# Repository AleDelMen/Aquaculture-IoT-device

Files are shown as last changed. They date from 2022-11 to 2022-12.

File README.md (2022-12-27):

# Design and development of a water quality measurement prototype for aquaculture production

This project presents the development of a system for monitoring and data collection. The system is composed of a device for measuring parameters related to a phenomenon of interest called end device, a gateway that is in charge of receiving the data, an application server that stores, displays and triggers alarms if necessary, and a network server that coordinates the gateway and the application server. As a demonstration of the system, a fish farm water quality monitoring application is shown, however, the proposed system is general purpose, and can be used in a wide variety of IoT applications.

## System operation

The block diagram of the project can be seen in the following figure. 

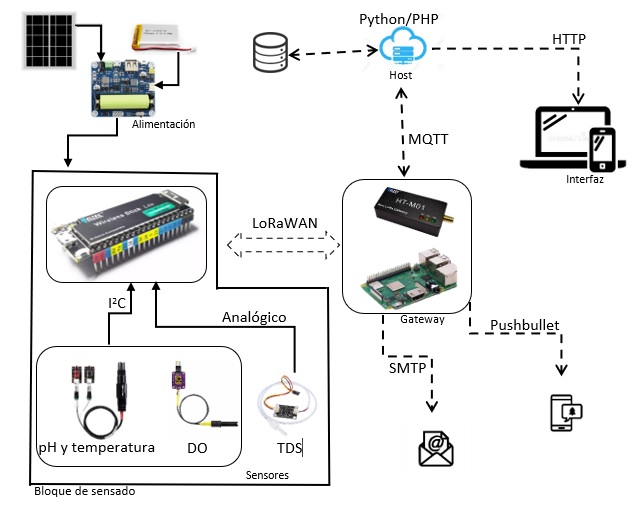
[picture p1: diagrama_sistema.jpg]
System diagram


The diagram shows that the sensing block is powered by solar panels or rechargeable batteries.
In this block, the Wireless Stick Lite board is in charge of controlling and collecting the information from the sensors through the i2c communication protocol and through an analog channel. Once the information is collected, it is transmitted from the control board to the gateway using the LoRaWAN protocol. 

The HT-M01 module controlled through a Raspberry Pi 3B+ was used as the gateway. The ChirpStack network server stack was also installed on the computer to carry out the LoRaWAN network implementation. The ChirpStack stack is responsible for sharing the information received from the sensing block to the host so that the host can process it. Chirpstack uses the MQTT protocol to communicate the data.

The host is in charge of processing the information through a Python script. If any irregularity is found in the data received, a digital alert is triggered and sent via email through the SMTP protocol or it can also be sent via push notification using the Pushbullet application. Additionally, the host is responsible for storing the information in a database and hosts a web page through which the data can be consulted in real time.

The web page was built using the adminLTE template as a base, together with HTML, CSS, native PHP, JavaScript, MariaDB technologies and phpMyAdmin was used as database manager. 

## Implementation
The water quality monitoring system developed in this work was implemented and evaluated in experimental shrimp, abalone, striped bass, koi carp and pismo clams farms located in the CICESE. Measurements were taken every minute, obtaining about 1440 samples per day versus two that are usually taken manually in these cultures.

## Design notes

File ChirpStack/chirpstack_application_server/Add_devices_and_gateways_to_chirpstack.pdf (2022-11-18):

# Add devices and gateways to ChirpStack

### October 2022

## 1 Create an organization

In order to add gateways and devices to ChirpStack, an organization needs to be created. Below are the steps to follow.

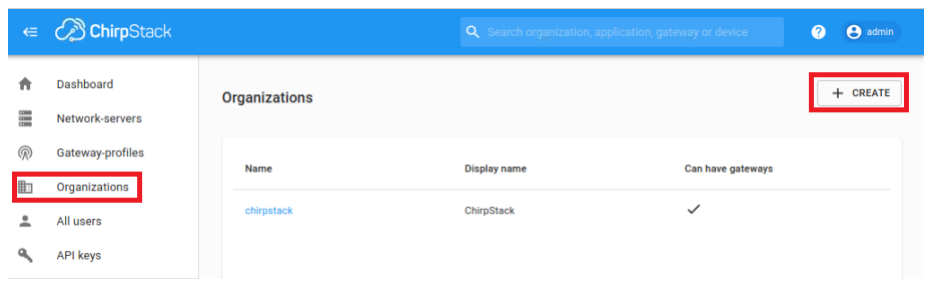
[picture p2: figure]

Figure 1: Tab to create an organization.

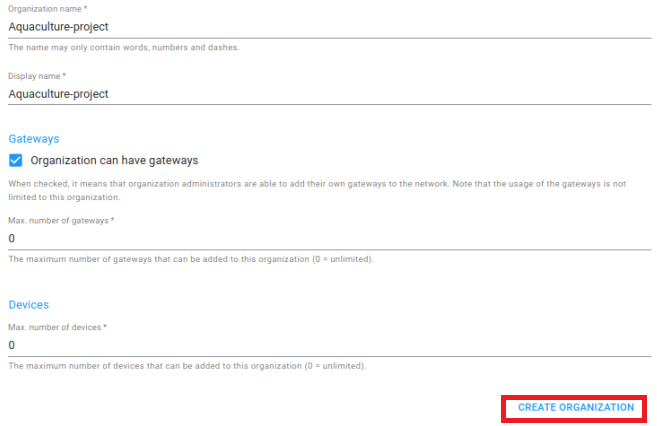
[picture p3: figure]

Figure 2: Fill in the organization data and press "create organization".

## 2 Create the Network Server

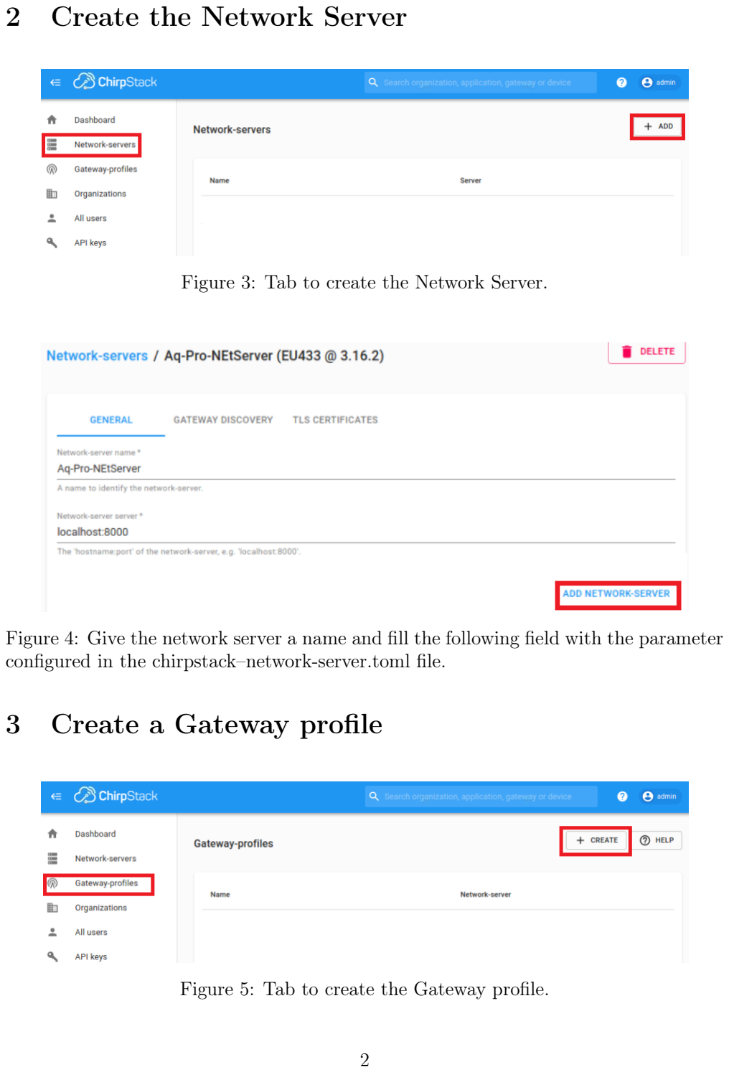
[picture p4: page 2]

Figure 3: Tab to create the Network Server.

Figure 4: Give the network server a name and fill the following field with the parameter configured in the chirpstack–network-server.toml file.

## 3 Create a Gateway profile

Figure 5: Tab to create the Gateway profile.

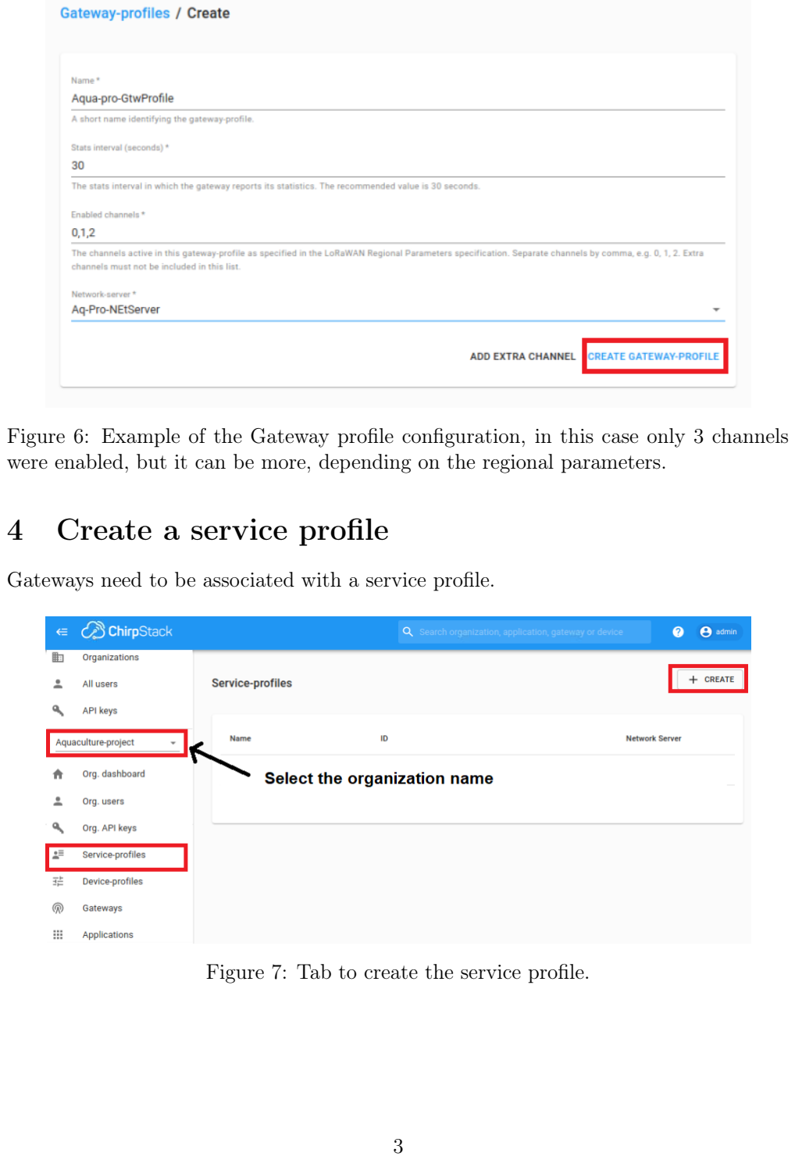
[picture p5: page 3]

Figure 6: Example of the Gateway profile configuration, in this case only 3 channels were enabled, but it can be more, depending on the regional parameters.

## 4 Create a service profile

Gateways need to be associated with a service profile.

Figure 7: Tab to create the service profile.

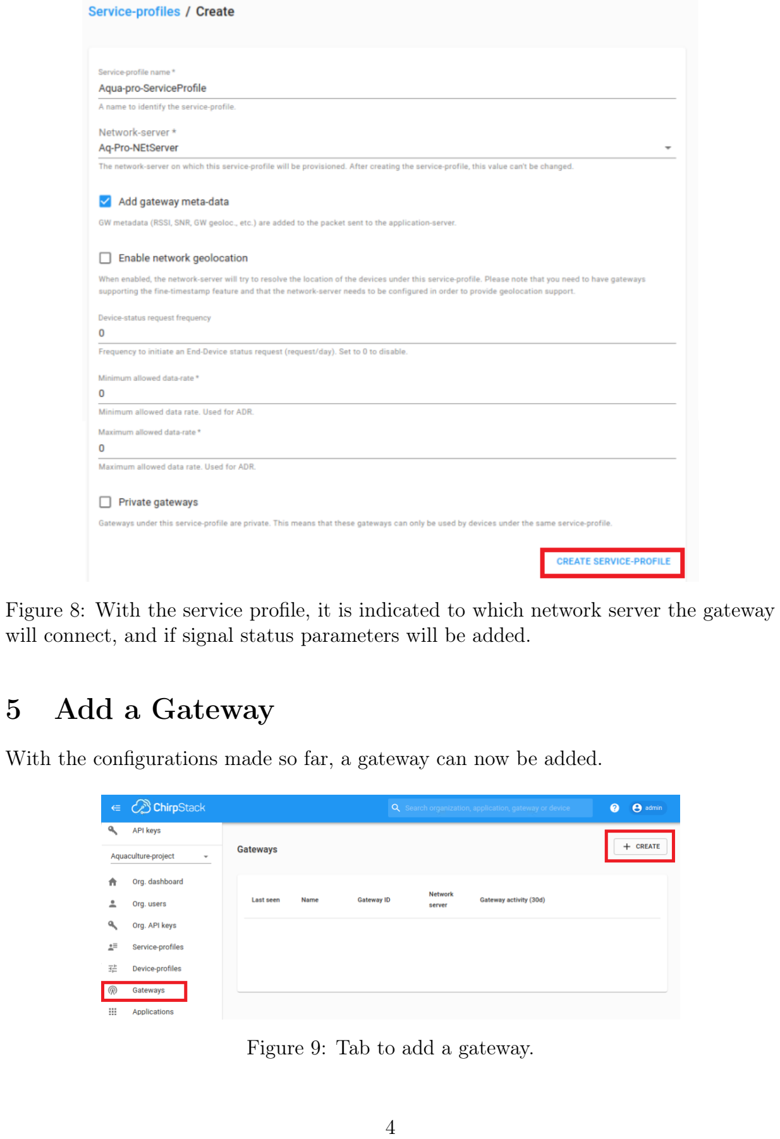
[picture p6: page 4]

Figure 8: With the service profile, it is indicated to which network server the gateway will connect, and if signal status parameters will be added.

## 5 Add a Gateway

With the configurations made so far, a gateway can now be added.

Figure 9: Tab to add a gateway.

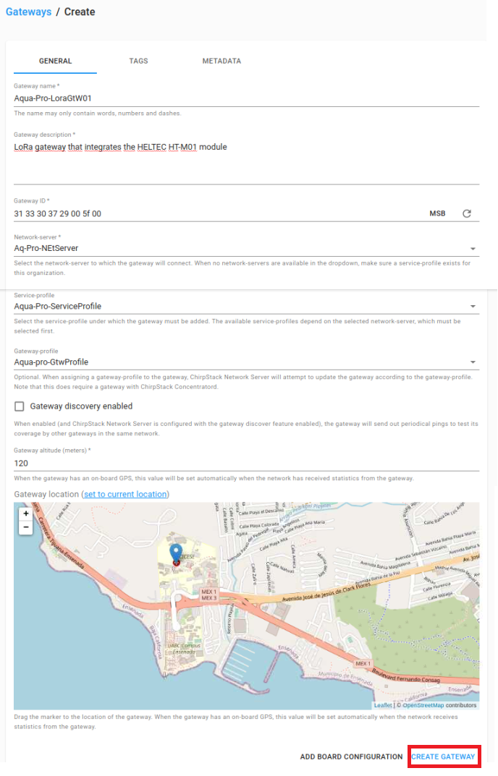
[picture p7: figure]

Figure 10: To add the gateway, all the previously created resources are needed, in addition to the Gateway_ID.

At the end of the registration process, it is possible to observe that the least seen status is a few seconds ago.

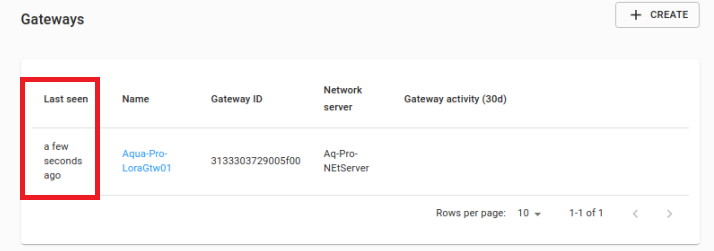
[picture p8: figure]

Figure 11: Gateway status at the end of the registration process.

It is also possible to see the status of the gateway in the main dashboard of the organization.

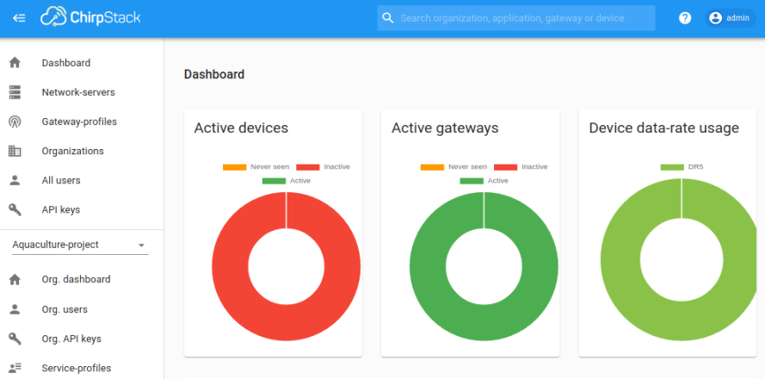
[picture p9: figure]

Figure 12: Gateway status on dashboard.

## 6 Create a device profile

To begin the process of registering a device on ChirpStack, you must already have the service profile. The device profile describes how to connect and authenticate a group of devices.

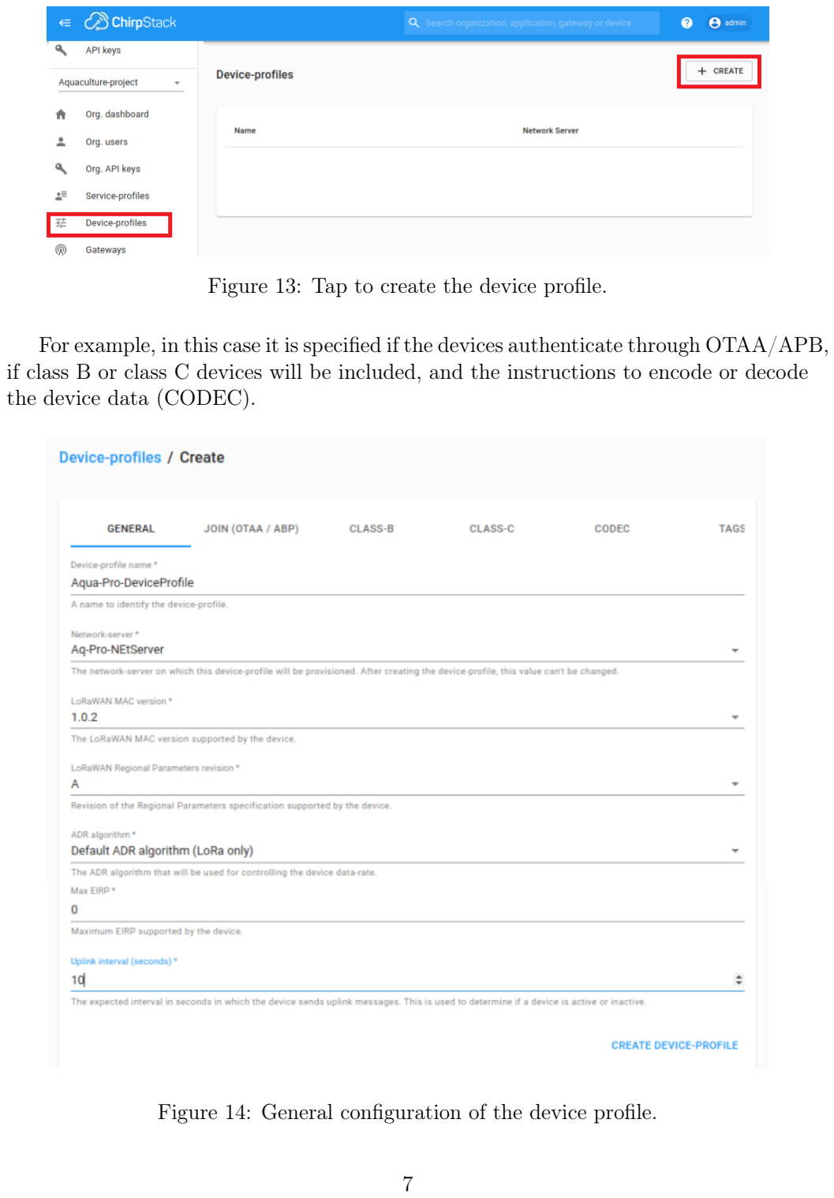
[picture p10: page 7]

Figure 13: Tap to create the device profile.

For example, in this case it is specified if the devices authenticate through OTAA/APB, if class B or class C devices will be included, and the instructions to encode or decode the device data (CODEC).

Figure 14: General configuration of the device profile.

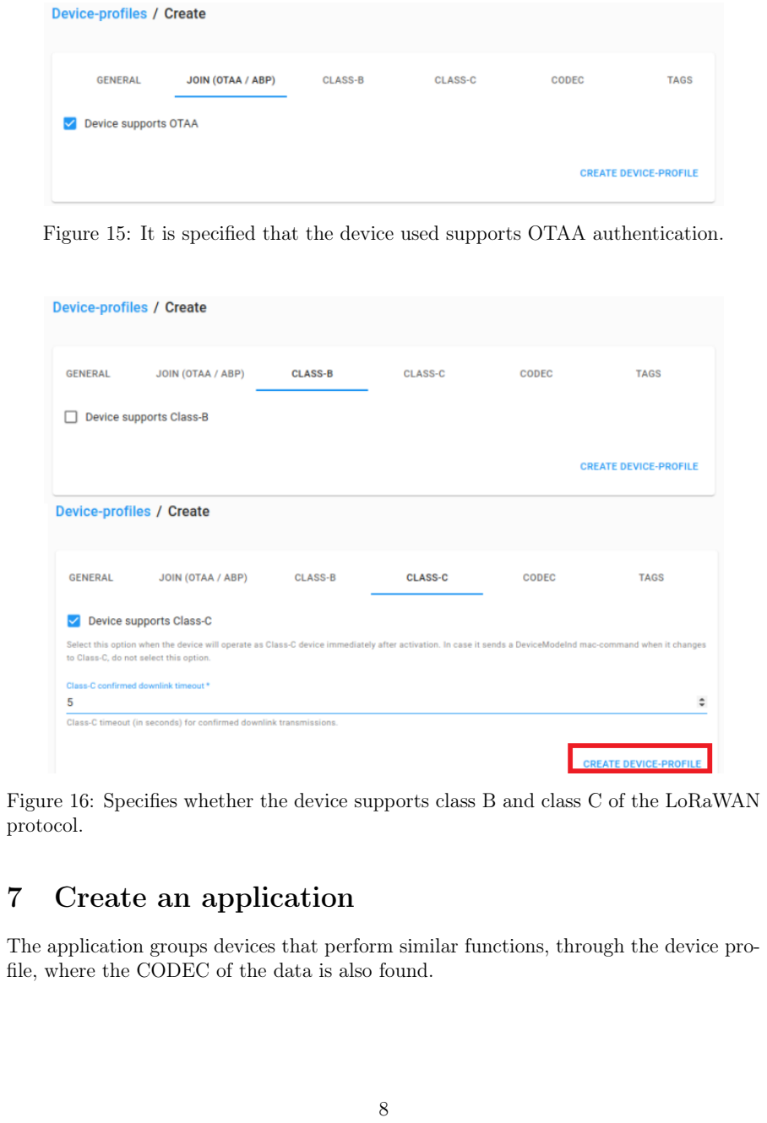
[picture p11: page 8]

Figure 15: It is specified that the device used supports OTAA authentication.

Figure 16: Specifies whether the device supports class B and class C of the LoRaWAN protocol.

## 7 Create an application

The application groups devices that perform similar functions, through the device profile, where the CODEC of the data is also found.

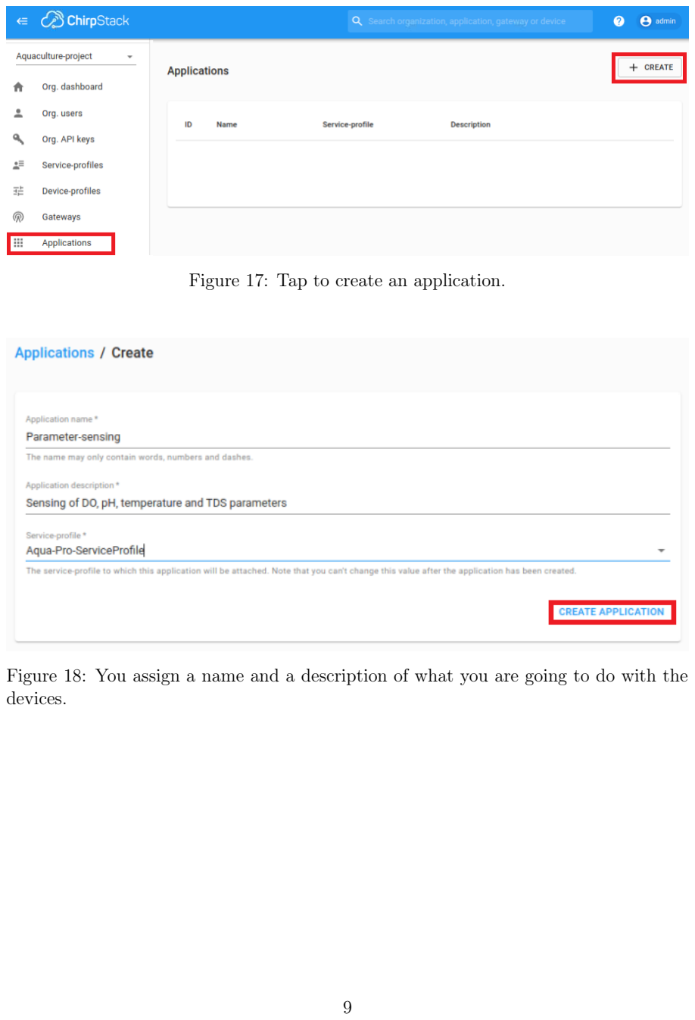
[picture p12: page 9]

Figure 17: Tap to create an application.

Figure 18: You assign a name and a description of what you are going to do with the devices.

## 8 Add devices to the app

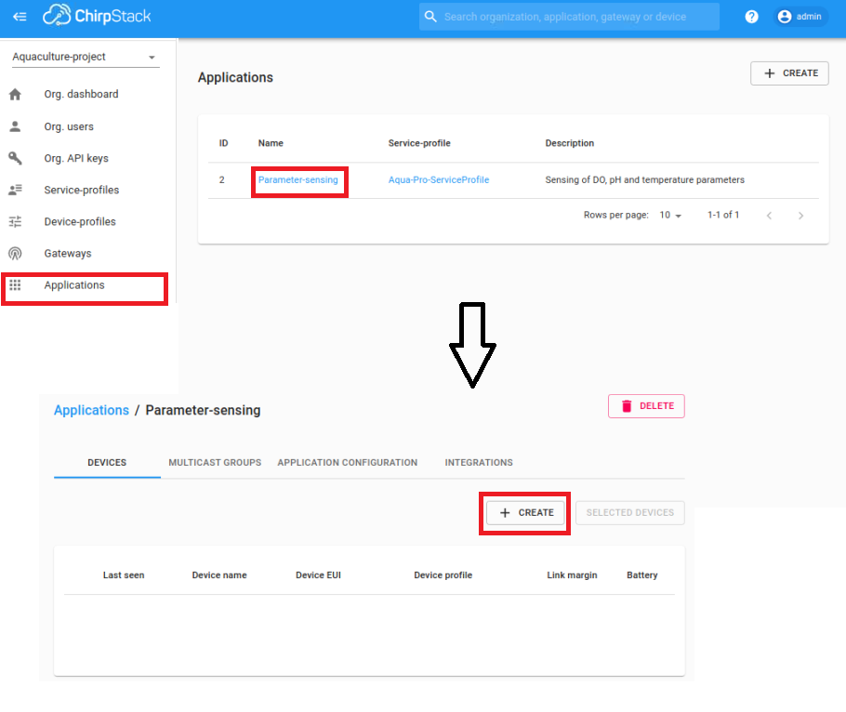
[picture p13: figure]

Figure 19: Path to follow to add devices to the app.

Device EUI is primary for OTAA connection. The Device EUI can be generated with the button displayed on the screen and is used in device programming.
The device profile is selected from the tab and the options are displayed.

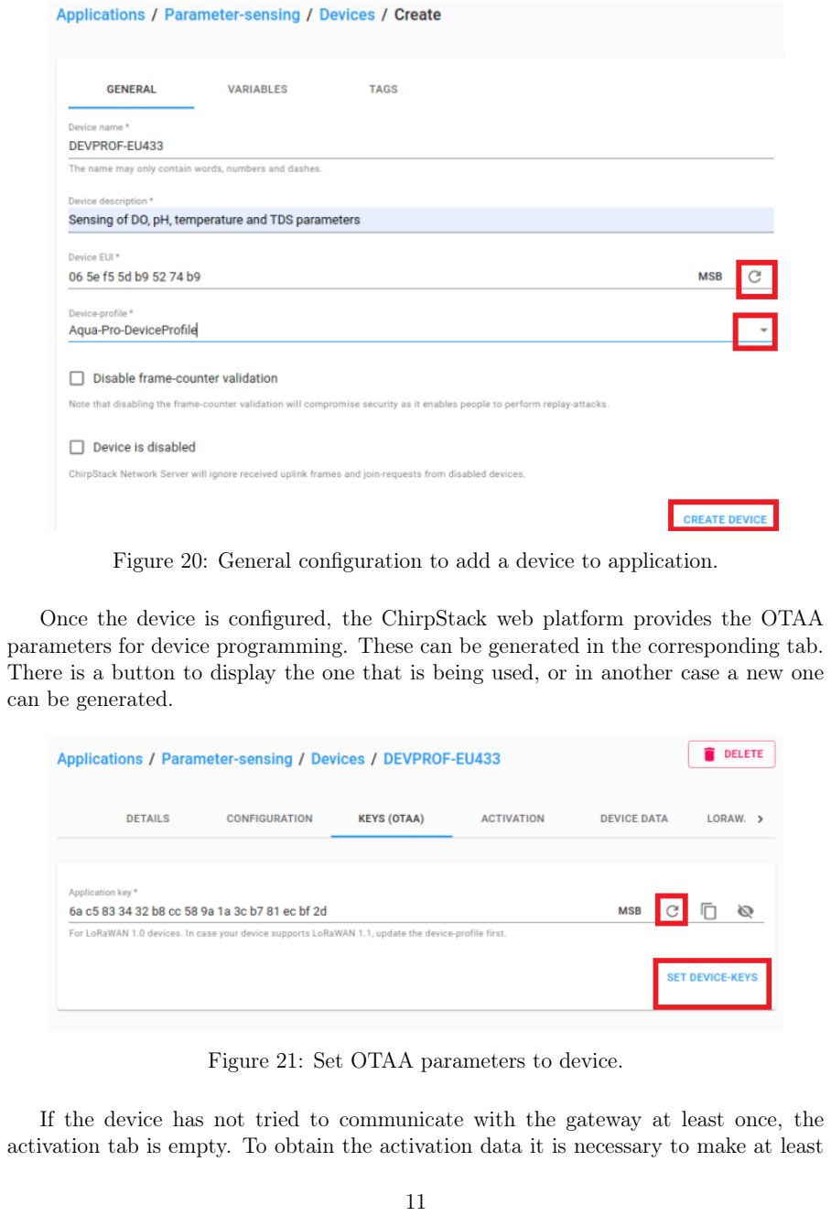
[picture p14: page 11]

Figure 20: General configuration to add a device to application.

Once the device is configured, the ChirpStack web platform provides the OTAA parameters for device programming. These can be generated in the corresponding tab. There is a button to display the one that is being used, or in another case a new one can be generated.

Figure 21: Set OTAA parameters to device.

If the device has not tried to communicate with the gateway at least once, the activation tab is empty. To obtain the activation data it is necessary to make at least

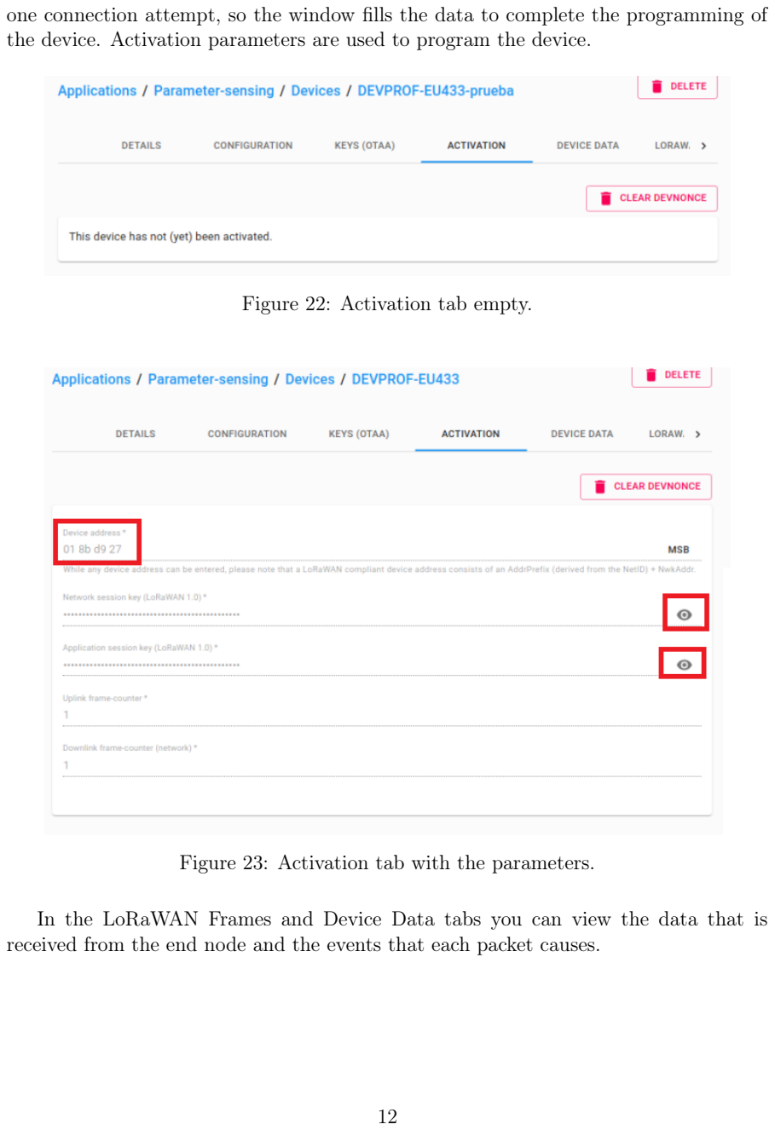
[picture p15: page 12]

one connection attempt, so the window fills the data to complete the programming of the device. Activation parameters are used to program the device.

Figure 22: Activation tab empty.

Figure 23: Activation tab with the parameters.

In the LoRaWAN Frames and Device Data tabs you can view the data that is received from the end node and the events that each packet causes.

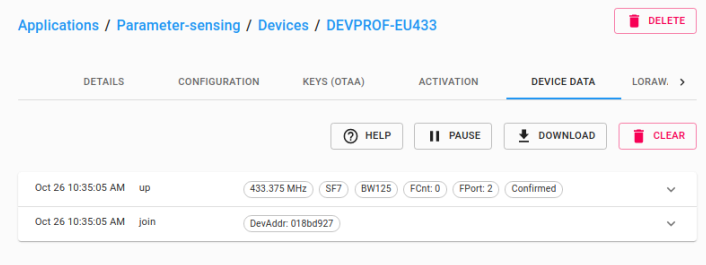
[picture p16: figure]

Figure 24: Device Data tab.

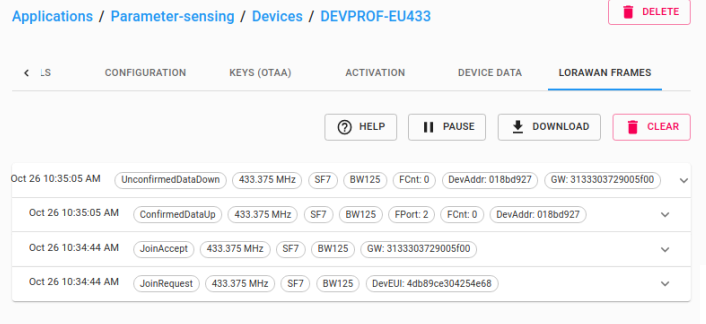
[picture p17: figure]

Figure 25: LoRaWAN Frames Tab.

It must be considered that the first time the device is connected, authentication may take a few attempts, so you have to wait for the data to start receiving, despite the fact that the LoRaWAN frames are registered in the program.
An example of programming code for a device can be seen in the repository https://github.com/AleDelMen/Aquaculture-IoT-device in the path Aquaculture-IoT-device → EndDevice → aquaculture_project.ino.

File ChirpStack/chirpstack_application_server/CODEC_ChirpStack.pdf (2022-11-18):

### How to access the section to define the CODEC in

ChirpStack.

November 2022

### 1 Go to device profiles

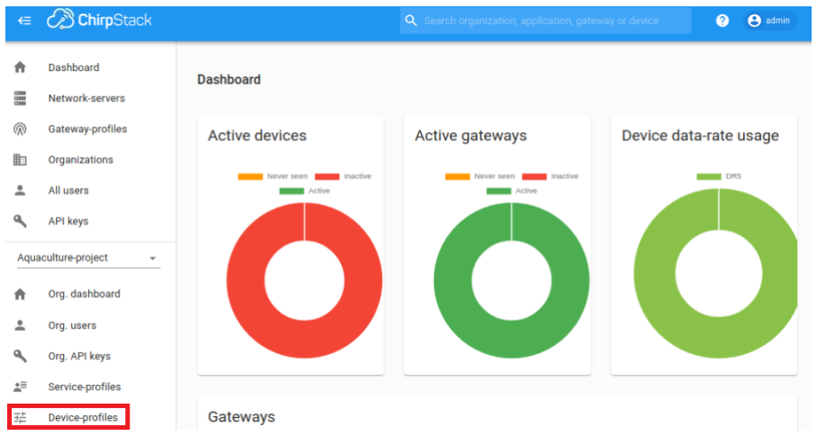
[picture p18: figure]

Figure 1: ChirpStack dashboard

### 2 Select the device profile to configure

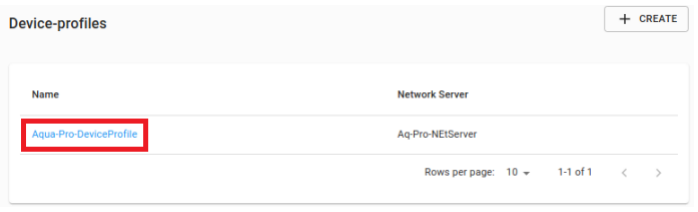
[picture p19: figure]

Figure 2: Device profiles tab

### 3 Select the codec tab

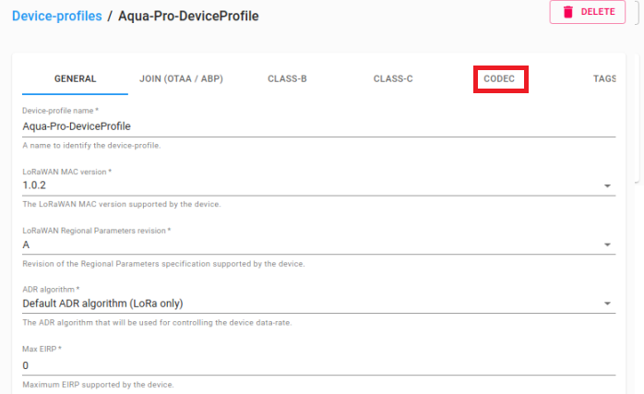
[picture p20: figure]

Figure 3: Device profile settings

### 4 In the dropdown menu select the Custom JavaScript

codec functions option

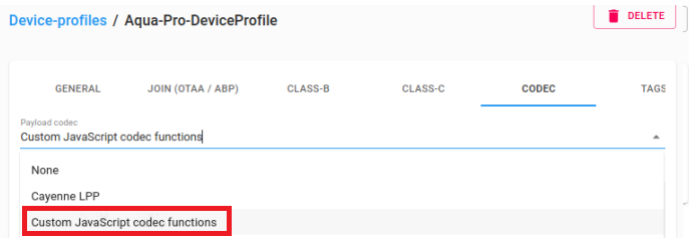
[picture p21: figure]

Figure 4: CODEC tab

### 5 Enter the code to decode and encode the informa-

tion.

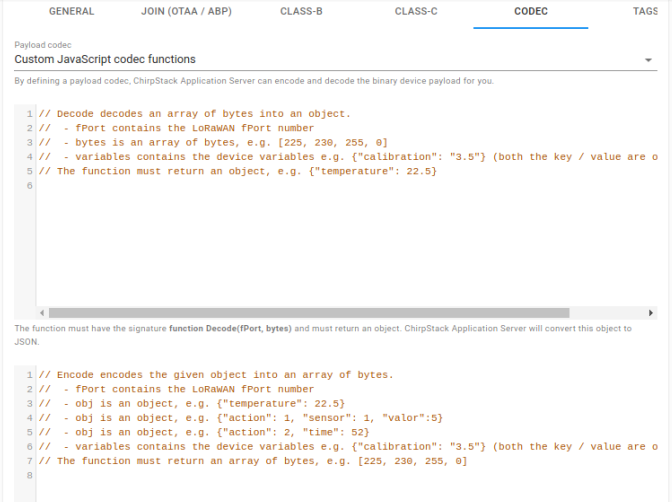
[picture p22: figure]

Figure 5: Section for programming the encode and decode functions in ChirpStack.

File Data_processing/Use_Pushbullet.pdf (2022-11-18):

# Use Pushbullet

### November 2022

## 1 Sign up to the Pushbullet platform through gmail

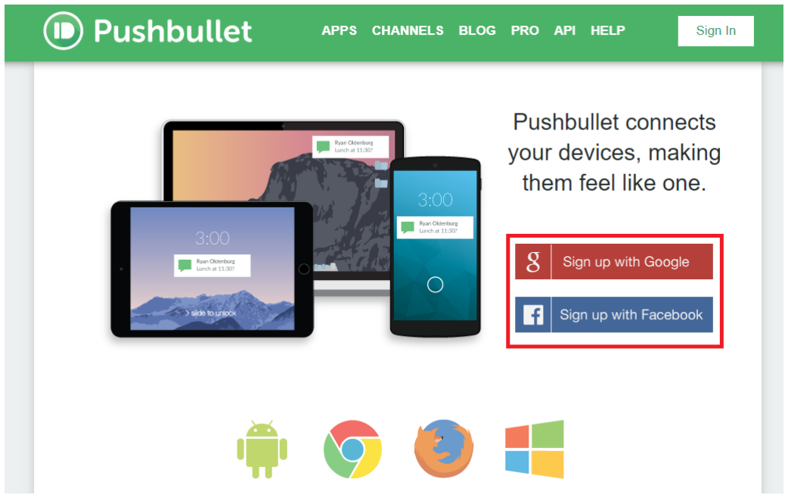
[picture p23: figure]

Figure 1: Pushbullet Home Page.

## 2 Enter the email and password of the account from which you will manage the notifications

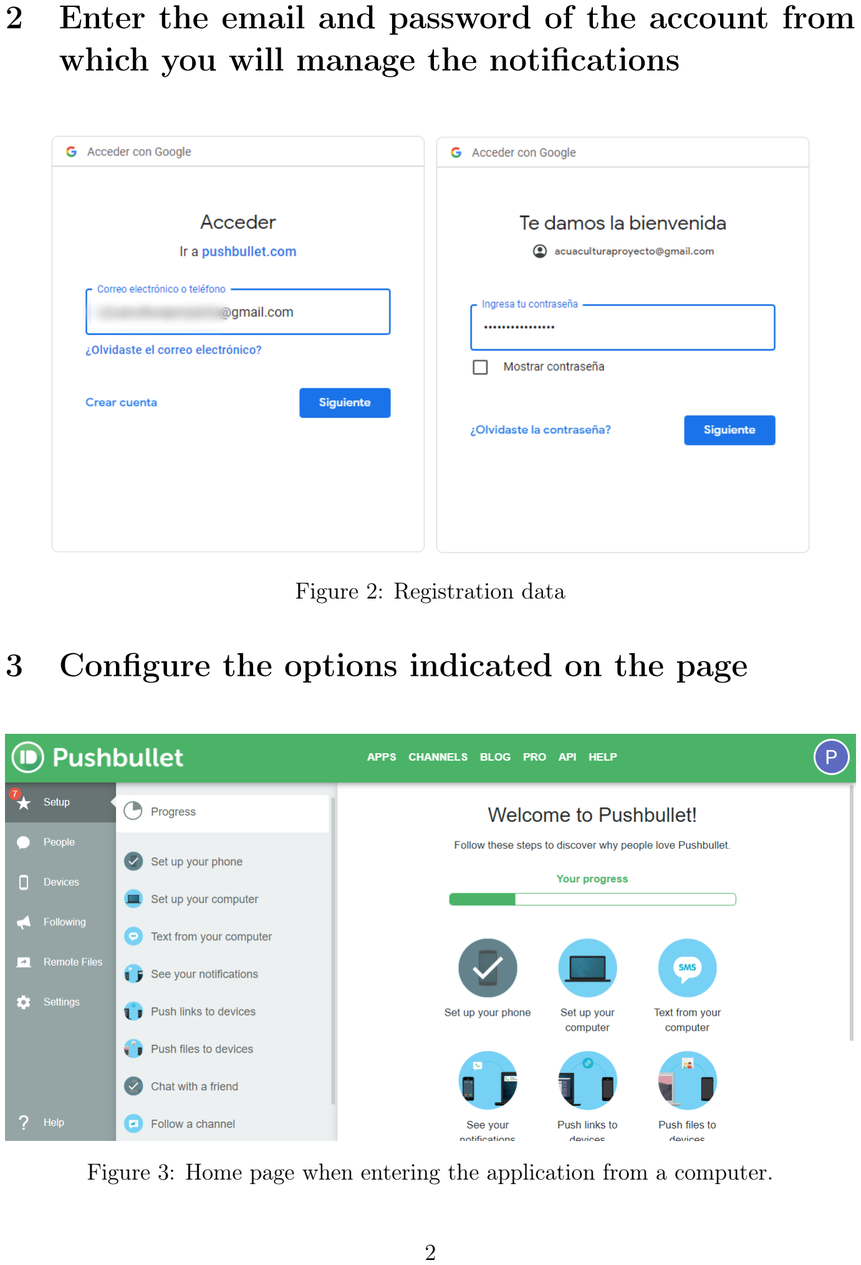
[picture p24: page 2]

Figure 2: Registration data

## 3 Configure the options indicated on the page

Figure 3: Home page when entering the application from a computer.

## 4 Install the Pushbullet application on the cell phone

and register with the personal gmail.

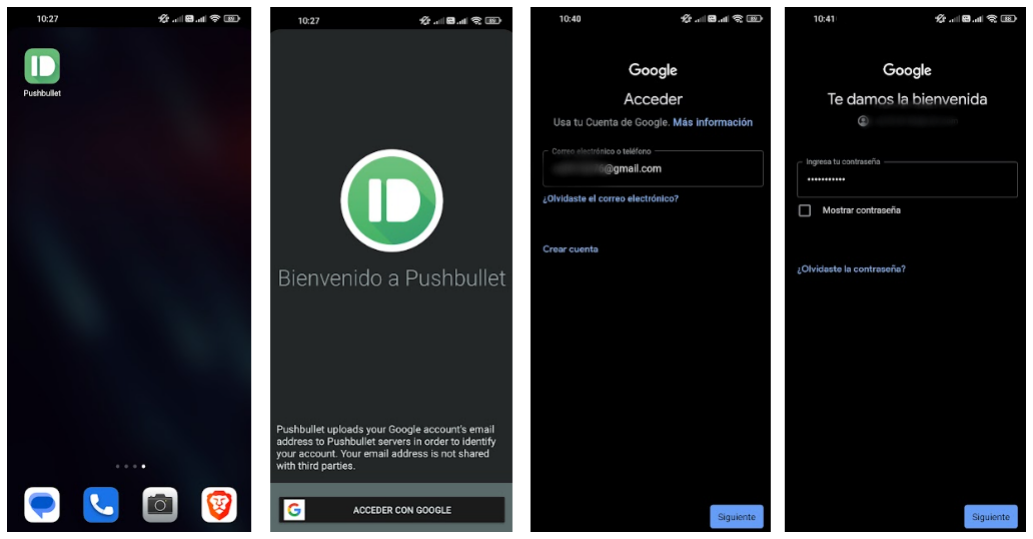
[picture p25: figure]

Figure 4: Registration process in the Pushbullet mobile application.

## 5 Accept Pushbullet permissions to access the Google

account.


Figure 5: Permissions that Pushbullet requires to work.

## 6 Other permissions requested by the application can

be denied.


Figure 6: Example of permission that the application can request.

## 7 When the installation process is complete, you will have the following view of the application


Figure 7: Main view from the mobile of the Pushbullet application

## 8 Once the above is done, it is necessary to add the contacts, in the desktop application, to whom the notifications will be made


Figure 8: Tab to add contacts.

## 9 Add a new contact

When you add a new contact, you can immediately start interacting with them through Pushbullet.


Figure 9: Process to add a new contact

## 10 Start sending push notifications


Figure 10: How a notification is sent via Pushbullet.

11 Push notification received.


Figure 11: Push notification received on the cell phone.

It is possible to manage the sending of push notifications through programming languages such as Python, since Pushbullet has an API. For this purpose an access token is needed which can be obtained in the Pushbullet desktop application.


Figure 12: Access Tokens

An example of implementing an alert system with Pushbullet can be seen in the repository https://github.com/AleDelMen/Aquaculture-IoT-device in the path Aquaculture-IoT-device → Data_processing → Integration_mqtt_db_pb_smtp.py.

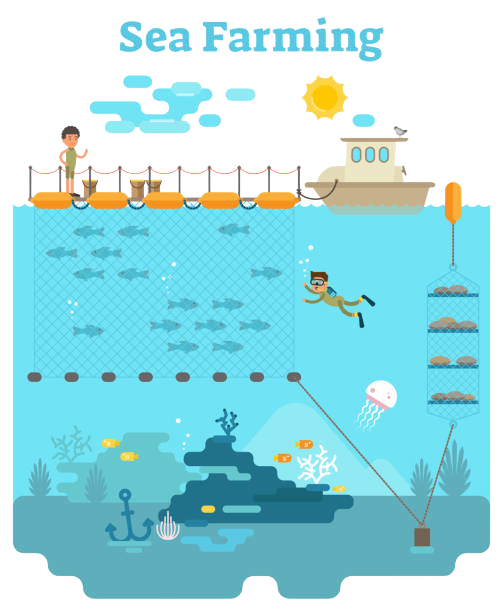
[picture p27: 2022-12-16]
WebServer/img/aqua7.png

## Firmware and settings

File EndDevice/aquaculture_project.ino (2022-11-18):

/*
 * HelTec Automation(TM) LoRaWAN 1.0.2 OTAA example use OTAA, CLASS A
 *
 * Function summary:
 *
 * - use internal RTC(150KHz);
 *
 * - Include stop mode and deep sleep mode;
 *
 * - Informations output via serial(115200);
 *
 * - Only ESP32 + LoRa series boards can use this library, need a license
 *   to make the code run(check you license here: http://www.heltec.cn/search );
 *
 * You can change some definition in "Commissioning.h" and "LoRaMac-definitions.h"
 *
 * HelTec AutoMation, Chengdu, China.
 * 成都惠利特自动化科技有限公司
 * https://heltec.org
 * support@heltec.cn
*/

//Imported libraries
#include <ESP32_LoRaWAN.h>  //This library is make LoRaWAN 1.0.2 protocol running with ESP32.
#include "Arduino.h"        //Main include file for the Arduino SDK
#include <EEPROM.h>         //brings in common print statements
#include <Ezo_i2c.h>        //include the EZO I2C library from https://github.com/Atlas-Scientific/Ezo_I2c_lib
#include <Wire.h>           //include arduinos i2c library
#include <Ezo_i2c_util.h>   //brings in common print statements

#define LORAWAN_DEFAULT_DATARATE                    DR_5
#define EEPROM_SIZE 12

//Multiplier parameter, to be able to use the lowbyte and highbyte functions
const int c = 1000;

//Pines used to enable/disable EZO's boards and TDS sensor.
int DO_trigger_int = 4;
gpio_num_t DO_trigger = (gpio_num_t)DO_trigger_int;

int PH_trigger_int = 2;
gpio_num_t PH_trigger = (gpio_num_t)PH_trigger_int;

int RTD_trigger_int = 15;
gpio_num_t RTD_trigger = (gpio_num_t)RTD_trigger_int;

int TDS_Isolator_int = 33;
int TDS_GND_Wire_int = 32;
gpio_num_t TDS_Isolator = (gpio_num_t)TDS_Isolator_int;
gpio_num_t TDS_GND_Wire = (gpio_num_t)TDS_GND_Wire_int;

//create a circuit object, who's address is XX and name is "BOAR_TYPE"
Ezo_board DO = Ezo_board(97, "DO");       
Ezo_board PH = Ezo_board(99, "PH");       
Ezo_board RTD = Ezo_board(102, "RTD");

//Parameters for the operation of the TDS sensor
#define TdsSensorPin 38 
#define VREF 3.3         // analog reference voltage(Volt) of the ADC
#define SCOUNT  30       // sum of sample point 
#define ADCRANGE 4095.0  

//Variables to store sensor data
float value_DO = 0.0;
float value_PH = 0.0;
float value_RTD = 0.0; 
float value_TDS = 0; 

//Variable for the minutes that pass between measurements and address where the variable is stored in the EEPROM
int minu;
int address = 0;
 
//License for Heltec ESP32 LoRaWan, quary your ChipID relevant license: http://resource.heltec.cn/search 
uint32_t  license[4] = {0xFEC7E5F8,0x1DC6E030,0xCAA96C89,0x692BB20A};

// OTAA parameters 
uint8_t DevEui[] = { 0x4d, 0xb8, 0x9c, 0xe3, 0x04, 0x25, 0x4e, 0x68 };
uint8_t AppEui[] = { 0x00, 0x00, 0x00, 0x00, 0x00, 0x00, 0x00, 0x00 };
uint8_t AppKey[] = { 0xf9, 0x4e, 0x3f, 0x87, 0xe4, 0xa6, 0x6d, 0xcb, 0x85, 0xe9, 0x1a, 0xba, 0x54, 0x22, 0x5c, 0x8b };

// ABP parameters 
//uint32_t DevAddr =  ( uint32_t )0x00425d48;
uint32_t DevAddr =  ( uint32_t )0x0033279e;

//uint8_t NwkSKey[] = { 0xb7, 0x75, 0x99, 0x0d, 0x1f, 0x99, 0xf7, 0xd4, 0x2b, 0x2b, 0x5c, 0x96, 0x77, 0x31, 0x09, 0x5d};
//uint8_t AppSKey[] = { 0x3e, 0x0b, 0x1a, 0x3f, 0x8e, 0xed, 0xc8, 0x59, 0x1d, 0x6c, 0xcd, 0x07, 0x5c, 0x81, 0xe6, 0x38};
                                                                                                                                                                                                                                                                                                                   
uint8_t NwkSKey[] = { 0x26, 0x60, 0x21, 0x5d, 0xd5, 0xd6, 0xb3, 0x26, 0x14, 0xa2, 0x3c, 0xd1, 0x64, 0x18, 0x3d, 0xbf};
uint8_t AppSKey[] = { 0x9d, 0xf7, 0x63, 0x38, 0x1a, 0x1b, 0xee, 0x85, 0xc8, 0x86, 0x15, 0xeb, 0x0f, 0xb8, 0xbc, 0x32};

/*LoraWan channelsmask*/
//It is indicated that only the first 3 channels will be used for communication
uint16_t userChannelsMask[6]={ 0x0007,0x0000,0x0000,0x0000,0x0000,0x0000 };

/*LoraWan Class, Class A and Class C are supported*/
DeviceClass_t  loraWanClass = CLASS_A;

/*the application data transmission duty cycle (value in [ms]).*/
uint32_t appTxDutyCycle;

/*OTAA or ABP*/
bool overTheAirActivation = true;

/*ADR enable*/
bool loraWanAdr = false;

/* Indicates if the node is sending confirmed or unconfirmed messages */
bool isTxConfirmed = true;

/* Application port */
uint8_t appPort = 2;

/*!
* Number of trials to transmit the frame, if the LoRaMAC layer did not
* receive an acknowledgment. The MAC performs a datarate adaptation,
* according to the LoRaWAN Specification V1.0.2, chapter 18.4, according
* to the following table:
*
* Transmission nb | Data Rate
* ----------------|-----------
* 1 (first)       | DR
* 2               | DR
* 3               | max(DR-1,0)
* 4               | max(DR-1,0)
* 5               | max(DR-2,0)
* 6               | max(DR-2,0)
* 7               | max(DR-3,0)
* 8               | max(DR-3,0)
*
* Note, that if NbTrials is set to 1 or 2, the MAC will not decrease
* the datarate, in case the LoRaMAC layer did not receive an acknowledgment
*/
uint8_t confirmedNbTrials = 3;

/*LoraWan debug level, select in arduino IDE tools.
* None : print basic info.
* Freq : print Tx and Rx freq, DR info.
* Freq && DIO : print Tx and Rx freq, DR, DIO0 interrupt and DIO1 interrupt info.
* Freq && DIO && PW: print Tx and Rx freq, DR, DIO0 interrupt, DIO1 interrupt and MCU deepsleep info.
*/
uint8_t debugLevel = LoRaWAN_DEBUG_LEVEL;

/*LoraWan region, select in arduino IDE tools*/
LoRaMacRegion_t loraWanRegion = ACTIVE_REGION;

//Function that calibrates the EZO boards as specified in the Atlas Scientific documentation
void calibrate_BOARD(Ezo_board BOARD, int sensor, int real_val, gpio_num_t trigger){
  gpio_hold_dis(trigger); 
  digitalWrite(trigger, LOW);  
  delay(2000);
  
  BOARD.send_cmd("Cal,clear");
  delay(600);

  int past_BOARDread;
  int current_BOARDread;
  int i = 0;

  BOARD.send_cmd("R");
  delay(1200);
  BOARD.send_read_cmd();
  delay(1200);
  receive_and_print_reading(BOARD);             //get the reading from the PH circuit
  past_BOARDread = BOARD.get_last_received_reading();
  delay(1000);

  while (i < 5){
    BOARD.send_cmd("R");
    delay(1200);
    BOARD.send_read_cmd();
    delay(1200);
    receive_and_print_reading(BOARD);             //get the reading from the PH circuit
    current_BOARDread = (int)BOARD.get_last_received_reading()*c;
    delay(1000);
    
    if(past_BOARDread == current_BOARDread){
      Serial.println("Las lecturas son las mismas, el valor de i es");
      i = i + 1;
      Serial.println(i);
    }
    else{
      Serial.println("Las lecturas noson las mismas, el valor de i es");
      i = 0;
      Serial.println(i);
      past_BOARDread = current_BOARDread;
    }
  }

  switch(sensor)
  {
    case 4:
    {
      if(real_val == 1){
        Serial.println("Se va a calibrar con empaque");
        BOARD.send_cmd("Cal,O");
        delay(2000);
      }
      if(real_val == 0){
        Serial.println("Se va a calibrar con el aire");
        BOARD.send_cmd("Cal");
        delay(2000);
      }
      break;
    }
    case 2:
    {
      if(real_val == 7){
        Serial.println("Se va a calibrar con empaque 7");
        BOARD.send_cmd("Cal,mid,7.00");
        delay(2000);
      }
      else if(real_val == 4){
        Serial.println("Se va a calibrar con empaque 4");
        BOARD.send_cmd("Cal,low,4.00");
        delay(2000);
      }
      if(real_val == 10){
        Serial.println("Se va a calibrar con empaque 10");
        BOARD.send_cmd("Cal,high,10.00");
        delay(2000);
      }
      break;
    }
    case 1:
    {
      Serial.println("Se va a calibrar RTD");
      float temperature = (float)real_val;
      String real_temp = String(temperature/1000);
      String command = "Cal,"+real_temp;
      char __command[sizeof(command)];
      command.toCharArray(__command, sizeof(__command));
      Serial.println("El comando seria");
      Serial.println(command);
      //const char *c = command.toCharArray();
      BOARD.send_cmd(__command);
      delay(2000);
      break;
    }
    default:
    {
      break;
    }
  }
  digitalWrite(trigger, HIGH);
  gpio_hold_en(trigger);
}

void action(uint8_t act, int arr[], int len){
  switch(act)
  {
    case 1:
    {
      if(len == 2){
        switch(arr[0])
        {
          case 4:
          {
            calibrate_BOARD(DO, 4, arr[1], DO_trigger);
            break;
          }
          case 2:
          {
            calibrate_BOARD(PH, 2, arr[1], PH_trigger);
            break;
          }
          case 1:
          {
            calibrate_BOARD(RTD, 1, arr[1], RTD_trigger);
            break;
          }
          default:
          {
            break;
          }
         }
      }
       break;
    }
    case 2:
    {
      if(len == 1){
        EEPROM.begin(EEPROM_SIZE);
        if(arr[0] > 1){
          EEPROM.put(address, arr[0]);
          EEPROM.commit();        
          EEPROM.get(address,minu);
          delay(10000);
        }
        else{
          EEPROM.put(address, 1);
          EEPROM.commit();
          EEPROM.get(address,minu);
          delay(10000);
        }
        EEPROM.end();
        appTxDutyCycle = minu * 60 * 1000;
      }
      break;
    }
    default:
    {
      break;
    }
   }
}

void  downLinkDataHandle(McpsIndication_t *mcpsIndication)
{
  lora_printf("+REV DATA:%s,RXSIZE %d,PORT %d\r\n",mcpsIndication->RxSlot?"RXWIN2":"RXWIN1",mcpsIndication->BufferSize,mcpsIndication->Port);

  uint8_t act = ((uint8_t)(mcpsIndication->Buffer[0]) << 8)
          + mcpsIndication->Buffer[1];
          
  int myVal = 0;
  int arr[((mcpsIndication->BufferSize) - 2)/2] = {};
  
  for(uint8_t i=1;i<=((mcpsIndication->BufferSize) - 2)/2;i = i + 1)
  {
    myVal = ((int)(mcpsIndication->Buffer[i*2]) << 8)
          + mcpsIndication->Buffer[i*2 + 1];
    arr[i - 1] = myVal;
  }
  int len = sizeof(arr) / sizeof(int);
  action(act, arr, len);
}

static void prepareTxFrame( uint8_t port )
{
    //Get RTD
    gpio_hold_dis(RTD_trigger); 
    digitalWrite(RTD_trigger, LOW);
    delay(2000);
    RTD.send_read_cmd();
    delay(815);
    //delay(1500);
    receive_and_print_reading(RTD);
    boolean success_temp = (RTD.get_error() == Ezo_board::SUCCESS) && (RTD.get_last_received_reading() > -1000.0);
    value_RTD = RTD.get_last_received_reading() * c;
    delay(815);
    digitalWrite(RTD_trigger, HIGH);
    gpio_hold_en(RTD_trigger); 
    
    //Get DO  
    gpio_hold_dis(DO_trigger); 
    digitalWrite(DO_trigger, LOW);  
    delay(2000);
    value_DO = get_value(DO, success_temp);
    digitalWrite(DO_trigger, HIGH);
    gpio_hold_en(DO_trigger); 

    //Get PH  
    gpio_hold_dis(PH_trigger); 
    digitalWrite(PH_trigger, LOW);  
    delay(2000);
    value_PH = get_value(PH, success_temp);
    digitalWrite(PH_trigger, HIGH);
    gpio_hold_en(PH_trigger); 

    //Get TDS
    gpio_hold_dis(TDS_Isolator);
    gpio_hold_dis(TDS_GND_Wire); 
    digitalWrite(TDS_Isolator,LOW); 
    digitalWrite(TDS_GND_Wire, HIGH);
    delay(1000);
    value_TDS = get_TDS() * c;
    digitalWrite(TDS_Isolator,HIGH); 
    digitalWrite(TDS_GND_Wire, LOW);
    gpio_hold_en(TDS_Isolator);
    gpio_hold_en(TDS_GND_Wire);

    appDataSize = 12;//AppDataSize max value is 64
    appData[0] = 1;
    appData[1] = highByte((int) value_RTD);
    appData[2] = lowByte((int) value_RTD);
    
    appData[3] = 4;
    appData[4] = highByte((int) value_DO);
    appData[5] = lowByte((int) value_DO);

    appData[6] = 2;
    appData[7] = highByte((int) value_PH);
    appData[8] = lowByte((int) value_PH);

    appData[9] = 3;
    appData[10] = highByte((int) value_TDS);
    appData[11] = lowByte((int) value_TDS);
}

float get_value(Ezo_board BOARD, boolean success_temp){
  if (success_temp) { //if the temperature reading has been received and it is valid
    BOARD.send_read_with_temp_comp(RTD.get_last_received_reading());                               //send readings from temp sensor to DO sensor
  }else {                                                                                      //if the temperature reading is invalid
    BOARD.send_read_with_temp_comp(25.0);                                                          //send default temp = 25 deg C to DO sensor
  }
  Serial.print(" ");
  delay(1000);
  receive_and_print_reading(BOARD);               //get the reading from the EC circuit and print it
  Serial.println();
  delay(2000);
  return BOARD.get_last_received_reading() * c;
}

float get_TDS(){
  int analogBuffer[SCOUNT];   // store the analog value in the array, read from ADC
  for (int i = 0; i < SCOUNT; i++)  //every 40 milliseconds,read the analog value from the ADC
  {
    analogBuffer[i] = analogRead(TdsSensorPin);    //read the analog value and store into the buffer
    delay(40U);
  }
  int analogBufferTemp[SCOUNT];
  for (int copyIndex = 0; copyIndex < SCOUNT; copyIndex++)
    analogBufferTemp[copyIndex] = analogBuffer[copyIndex];
  float averageVoltage = getMedianNum(analogBufferTemp, SCOUNT) * (float)VREF / ADCRANGE; // read the analog value more stable by the median filtering algorithm, and convert to voltage value      
  return averageVoltage;
}

int getMedianNum(int bArray[], int iFilterLen)
{
  int bTab[iFilterLen];
  for (byte i = 0; i < iFilterLen; i++)
    bTab[i] = bArray[i];
  int i, j, bTemp;
  for (j = 0; j < iFilterLen - 1; j++)
  {
    for (i = 0; i < iFilterLen - j - 1; i++)
    {
      if (bTab[i] > bTab[i + 1])
      {
        bTemp = bTab[i];
        bTab[i] = bTab[i + 1];
        bTab[i + 1] = bTemp;
      }
    }
  }
  if ((iFilterLen & 1) > 0)
    bTemp = bTab[(iFilterLen - 1) / 2];
  else
    bTemp = (bTab[iFilterLen / 2] + bTab[iFilterLen / 2 - 1]) / 2;
  return bTemp;
}

void setup()
{
  Wire.begin();                           //start the I2C
  Serial.begin(115200);
  while (!Serial);
  SPI.begin(SCK,MISO,MOSI,SS);
  Mcu.init(SS,RST_LoRa,DIO0,DIO1,license);
  deviceState = DEVICE_STATE_INIT;

  //Init EEPROM
  EEPROM.begin(EEPROM_SIZE);
  EEPROM.get(address,minu);
  EEPROM.end();
  
  appTxDutyCycle = minu * 60 * 1000;
  //appTxDutyCycle = 0.1 * 60 * 1000;

  pinMode(TdsSensorPin, INPUT);

  pinMode(DO_trigger, OUTPUT);
  pinMode(PH_trigger, OUTPUT);
  pinMode(RTD_trigger, OUTPUT); 
  pinMode(TDS_Isolator, OUTPUT); 
  pinMode(TDS_GND_Wire, OUTPUT);

  digitalWrite(RTD_trigger, HIGH);
  gpio_hold_en(RTD_trigger);
  digitalWrite(DO_trigger, HIGH);
  gpio_hold_en(DO_trigger);
  digitalWrite(PH_trigger, HIGH);
  gpio_hold_en(PH_trigger);
  digitalWrite(TDS_Isolator,HIGH); 
  digitalWrite(TDS_GND_Wire, LOW);
  gpio_hold_en(TDS_Isolator);
  gpio_hold_en(TDS_GND_Wire);
}

// The loop function is called in an endless loop
void loop()
{
  switch( deviceState )
  {
    case DEVICE_STATE_INIT:
    {
#if(LORAWAN_DEVEUI_AUTO)
      LoRaWAN.generateDeveuiByChipID();
#endif
      LoRaWAN.init(loraWanClass,loraWanRegion);
      break;
    }
    case DEVICE_STATE_JOIN:
    {
      LoRaWAN.join();
      break;
    }
    case DEVICE_STATE_SEND:
    {
      prepareTxFrame( appPort );
      LoRaWAN.send(loraWanClass);
      deviceState = DEVICE_STATE_CYCLE;
      break;
    }
    case DEVICE_STATE_CYCLE:
    {
      // Schedule next packet transmission
      txDutyCycleTime = appTxDutyCycle + randr( -APP_TX_DUTYCYCLE_RND, APP_TX_DUTYCYCLE_RND );
      LoRaWAN.cycle(txDutyCycleTime);
      deviceState = DEVICE_STATE_SLEEP;
      break;
    }
    case DEVICE_STATE_SLEEP:
    {
      LoRaWAN.sleep(loraWanClass,debugLevel);
      break;
    }
    default:
    {
      deviceState = DEVICE_STATE_INIT;
      break;
    }
  }
}

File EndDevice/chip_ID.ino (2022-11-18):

/* The true ESP32 chip ID is essentially its MAC address.
This sketch provides an alternate chip ID that matches 
the output of the ESP.getChipId() function on ESP8266 
(i.e. a 32-bit integer matching the last 3 bytes of 
the MAC address. This is less unique than the 
MAC address chip ID, but is helpful when you need 
an identifier that can be no more than a 32-bit integer 
(like for switch...case).
created 2020-06-07 by cweinhofer
with help from Cicicok */
  
uint64_t chipId = 0;

void setup() {
  Serial.begin(115200);
}

void loop() {
//    chipId |= ((ESP.getEfuseMac() >> (40 - i)) & 0xff) << i;
  chipId=ESP.getEfuseMac();//The chip ID is essentially its MAC address(length: 6 bytes).
  Serial.printf("ESP32ChipID=%04X",(uint16_t)(chipId>>32));//print High 2 bytes
  Serial.printf("%08X\n",(uint32_t)chipId);//print Low 4bytes.

//  Serial.printf("ESP32 Chip model = %s Rev %d\n", ESP.getChipModel(), ESP.getChipRevision());
//  Serial.printf("This chip has %d cores\n", ESP.getChipCores());
//  Serial.print("Chip ID: "); Serial.println(chipId);
  
  delay(3000);

}
